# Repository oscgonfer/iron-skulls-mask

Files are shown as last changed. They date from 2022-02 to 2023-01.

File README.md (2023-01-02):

# Iron Skulls Mask - Azul Petróleo

Code and hardware repository for Iron Skulls Azul Petróleo Mask.

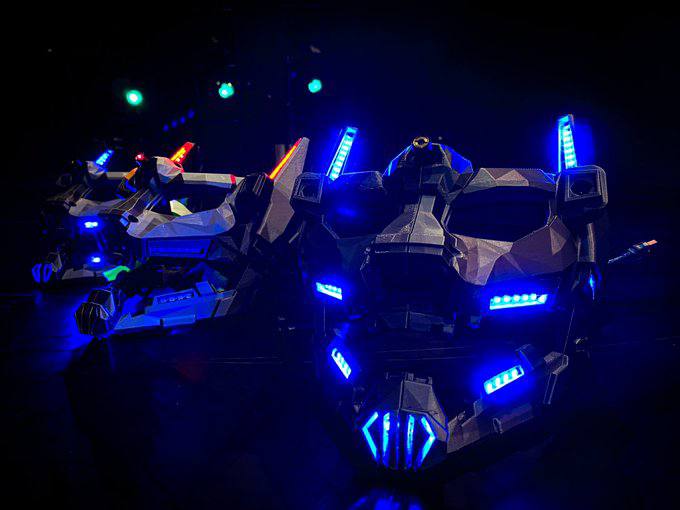
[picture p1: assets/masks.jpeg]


## Model

The mask can be 3D printed in two halves ([left](model/Mask_left.stl) and [right](model/Mask_right.stl)) with supports. Use at least 20% infill to avoid problems in the jaw connection. Both halves can be joined with M3 screws with inserts.

## Electronics

There are 45 addressable RGB LEDs (144led/m, skinny type from [Adafruit](https://www.adafruit.com/product/2969)), 2 very high power [white LEDs](https://www.adafruit.com/product/518) (discontinued?) and 1 [laser pointer](https://www.adafruit.com/product/1056). Everything is controlled by a Feather M0 board, with a RFM69 433MHz radio and powered by a 2000mAh LiPo battery. A shield is used to control the different elements. In addition, an [external antenna](https://www.mouser.es/ProductDetail/815-CAC053010-S433) is used for enhanced reach.

- RGB LEDs are powered directly from the battery, controlled with a single pin from the Feather
- The two high power LEDs are controlled via mosfet, in parallel. The LEDs neeed 3.3V, so a high power LDO is necessary
- The laser is controlled via PWM

A bill of materials is found in the [`hardware/controller`](hardware/controller) folder as well as pcb designs for the feather's shield. The kicad files say it's a Atmega 32u4, which can be, but better to use the Atmel SAMD21 (M0) for the extra Flash memory.

### Power

The feather handles battery charge via it's on board charger. The mask is charged via USB.
Since there are so many LEDs, **at least a 0.5C fast discharge rate battery** is necessary if everything is on. This means that the battery will last 2h at this discharge rate, otherwise, at 0.2C (normal rate), it will last 5h:

| Type | Ratio | Max. Current | Duration (theory) |
| --- | --- | --- | --- |
| Normal | 0.2C | 400mA | 5h |
| Fast | 0.5C | 1A | 2h |

The mask hasn't been tested for full power continuous operation for more than minutes, but it does last >6h in normal operation (not everything on at the same time, all the time).

## Control

The control follows a client-server architecture. Each mask is a server, with an address, and there is a client connected to a computer via USB. The code in both ends is _asynchronous_ so that messages can be sent and arrive to the masks at any time and be responsive.

### Client side

A python script listens to UDP messages and forwards them to a Feather M0 board via USB. This is the [Feather client code](radio/client) (platformio needed). This is the [python script](radio/bridge/bridge.py), using python AsyncIO for serial and OSC/UDP server.

### Server side

A similar code listens on the servers:

- Radiohead is used for receiving packets
- The RGB leds are managed using [NeoPixelBus](https://github.com/Makuna/NeoPixelBus)
- The two high power LEDs and the LED are managed using [JLED](https://github.com/jandelgado/jled)

Animations are static, triggered by a string received via radio, and are stored in [`Animations.h`](radio/server/src/Animations.h). There is a table for describing how the animations are encoded [here](radio/server/src/ANIMATIONS.md).

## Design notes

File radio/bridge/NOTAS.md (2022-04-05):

NOTAS

Hacer los SLINKS (OSC) con WAIT=0, todo con GO

PERRO
Frontales limitarlos hasta acción? o hacerlos cara a público
Interacción laser compleja
Parte final con espacio muy abierto - introducir calles y usar más contra 603

XALAPA
Continuar con mismo ambiente

FINAL XAPALA IR CERRANDO EN EN CENTRO? CHASE?

DIEGO - GUITARRA
Reducir intensidad
CALIDO - INTIMO ---> Hacerlo con convencional en lugar de LED

NOTAS

TODO EN GENERAL MUY ABIERTO
CALLE LATERAL BIEN
CUANDO ENTRA LA MASCARA

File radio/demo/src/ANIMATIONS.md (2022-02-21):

## LEDSTRIP ANIMATIONS

__ __ __
|  |  |
|  |  |__ F: FAST / S: SLOW
|  |
|  |__ F: FADE / L: LOOP
|
|__ A: ALL / E: EYES / O: EARS

### Full Table

| CODE | DESCRIPTION | PARAM |
| :-: | :- | :- |
| "AFF"  | ALL FADE FAST | COLOR (RGB_HEX) |
| "AFS"  | ALL FADE SLOW | COLOR (RGB_HEX) |
| "ALF"  | ALL LOOP FAST | COLOR (RGB_HEX) |
| "ALS"  | ALL LOOP SLOW | COLOR (RGB_HEX) |
| "EFF"  | EYES FADE FAST | COLOR (RGB_HEX) |
| "EFS"  | EYES FADE SLOW | COLOR (RGB_HEX) |
| "ELF"  | EYES LOOP FAST | COLOR (RGB_HEX) |
| "ELS"  | EYES LOOP SLOW | COLOR (RGB_HEX) |
| "OFF"  | EARS FADE FAST | COLOR (RGB_HEX) |
| "OFS"  | EARS FADE SLOW | COLOR (RGB_HEX) |
| "OLF"  | EARS LOOP FAST | COLOR (RGB_HEX) |
| "OLS"  | EARS LOOP SLOW | COLOR (RGB_HEX) |

### Example

```
AFF/00FF00
--> All Leds Fade-in to Green
```

## PWM ANIMATIONS (LASER OR HIGH POWER LEDS)

__ __ __
|  |  |
|  |  |__ S: SHOT / F: FOREVER
|  |
|  |__ F: FADE / R: BREATHE / L: BLINK
|
|__ L: LASER / F: FRONTLIGHTS

### Full Table

| CODE | DESCRIPTION | PARAM | 
| :-: | :- | :- |
| "LFF"  | LASER FADE-TO FAST | INTENSITY |
| "LFS"  | LASER FADE-TO SLOW | INTENSITY |
| "LRF"  | LASER BREATH FOREVER | PERIOD |
| "LLF"  | LASER BLINK FOREVER | PERIOD |
| "LRS"  | LASER BREATH SHOT_NUM-SHOTs | PERIOD |
| "LLS"  | LASER BLINK SHOT_NUM-SHOTs | PERIOD |
| "FFF"  | FRONT FADE-TO FAST | INTENSITY |
| "FFS"  | FRONT FADE-TO SLOW | INTENSITY |
| "FRF"  | FRONT BREATH FOREVER | PERIOD |
| "FLF"  | FRONT BLINK FOREVER | PERIOD |
| "FRS"  | FRONT BREATH SHOT_NUM-SHOTs | PERIOD |
| "FLS"  | FRONT BLINK SHOT_NUM-SHOTs | PERIOD |

### Example

```
FRF/3000
--> Front Lights Breathe Forever with 3000ms PERIOD
```

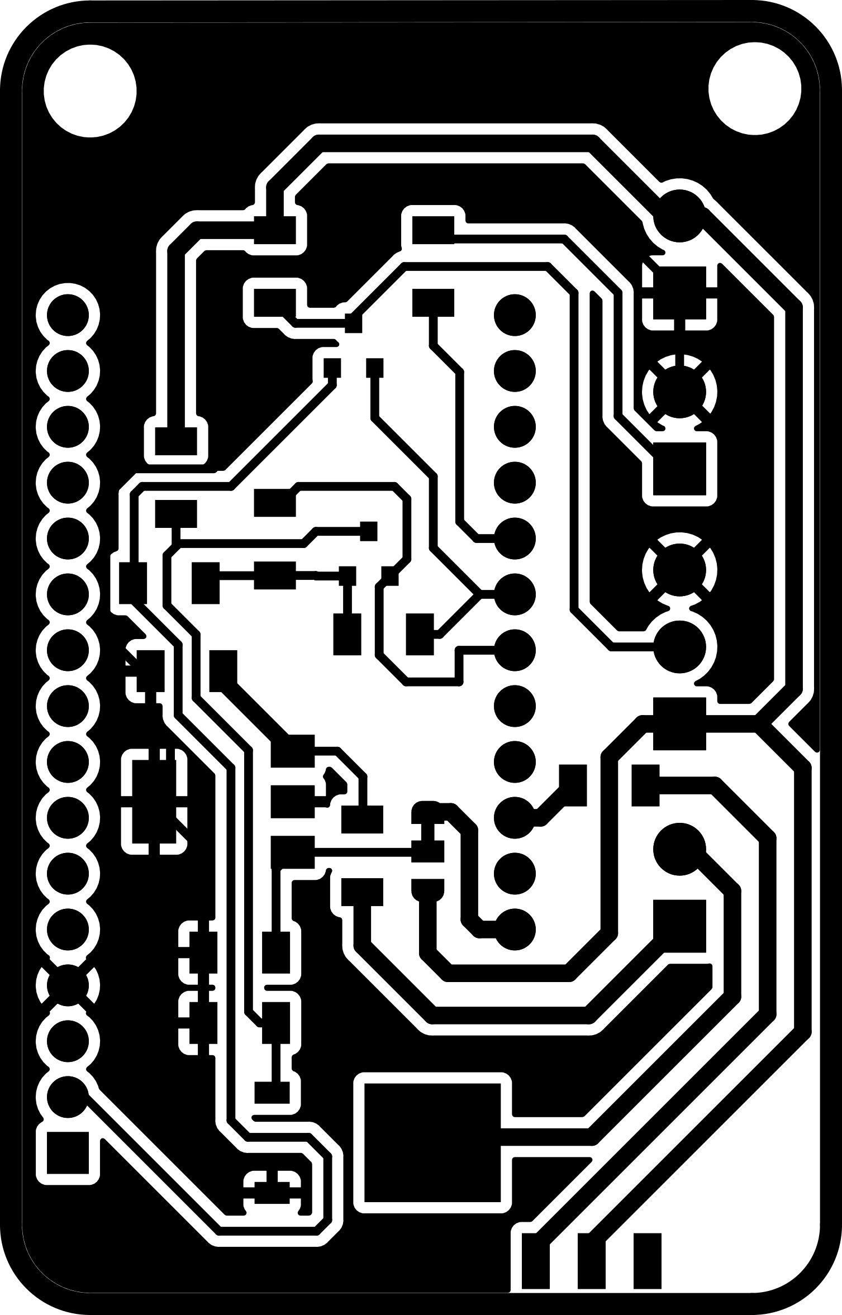
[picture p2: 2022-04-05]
hardware/controller/exports/fab/traces_2.png

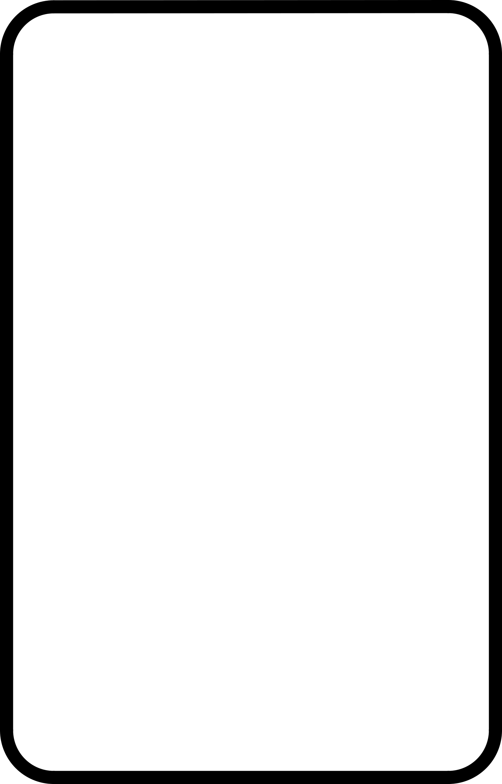
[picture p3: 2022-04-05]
hardware/controller/exports/fab/outline_2.png

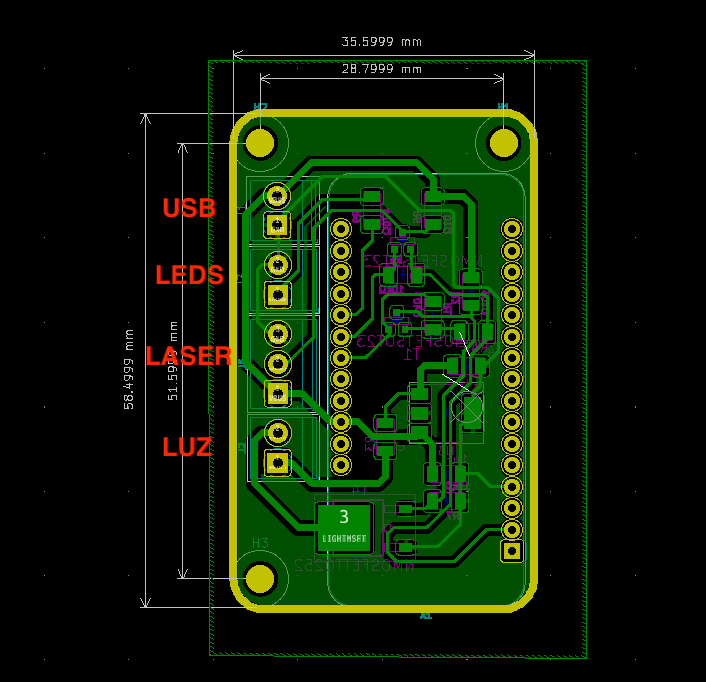
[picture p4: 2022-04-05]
hardware/controller/exports/fab/esquema.png

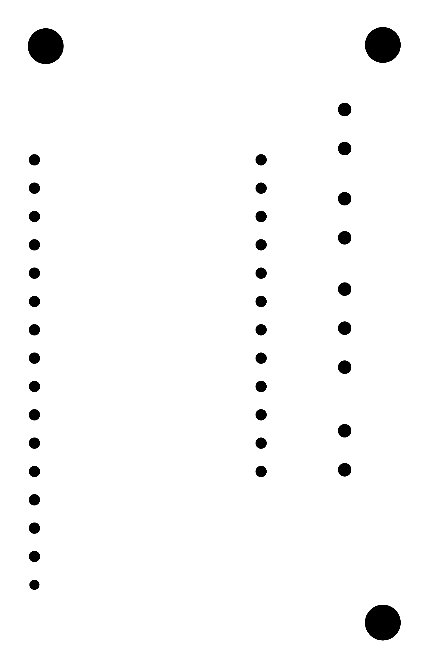
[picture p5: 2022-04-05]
hardware/controller/exports/fab/holes_2.png

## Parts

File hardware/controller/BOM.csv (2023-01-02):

SHIELD
Item | Qty | Reference(s) | Value | LibPart | Footprint | Datasheet
1 | 1 | A1 | Adafruit_Feather_32u4_BluefruitLE | MCU_Module:Adafruit_Feather_32u4_BluefruitLE | Module:Adafruit_Feather | https://cdn-learn.adafruit.com/downloads/pdf/adafruit-feather-32u4-bluefruit-le.pdf
2 | 1 | C3 | 1uF | fab:CAP-UNPOLARIZEDFAB | fab-C1206FAB
3 | 1 | C4 | 4.7uF | fab:CAP-UNPOLARIZEDFAB | fab-C1206FAB
4 | 3 | H1, H2, H3 | MountingHole | Mechanical:MountingHole | MountingHole:MountingHole_3.2mm_M3 | ~
5 | 3 | J1, J2, J3 | Screw_Terminal_01x02 | Connector:Screw_Terminal_01x02 | TerminalBlock_Phoenix:TerminalBlock_Phoenix_PT-1,5-2-3.5-H_1x02_P3.50mm_Horizontal | ~
6 | 1 | J5 | Screw_Terminal_01x03 | Connector:Screw_Terminal_01x03 | TerminalBlock_Phoenix:TerminalBlock_Phoenix_PT-1,5-3-3.5-H_1x03_P3.50mm_Horizontal | ~
7 | 1 | JP1 | Jumper_3_Bridged12 | Jumper:Jumper_3_Bridged12 | Jumper:SolderJumper-3_P1.3mm_Bridged12_RoundedPad1.0x1.5mm_NumberLabels | ~
8 | 5 | R1, R2, R5, R6, R7 | 10kΩ | Device:R_US | fab:fab-R1206FAB | ~
9 | 3 | R3, R4, R8 | 0 | Device:R_US | fab:fab-R1206FAB | ~
10 | 1 | R9 | 470Ω | Device:R_US | fab:fab-R1206FAB | ~
11 | 1 | SW1 | SW_SPDT | Switch:SW_SPDT | fab:fab-SPDTSWITCH | ~
12 | 2 | T1, T3 | NMOSFETSOT23 | fab:NMOSFETSOT23 | fab-SOT-23
13 | 1 | T4 | NMOSFETTO252 | fab:NMOSFETTO252 | fab-TO252
14 | 1 | U3 | AP7361C-33E | Regulator_Linear:AP7361C-33E | Package_TO_SOT_SMD:SOT-223-3_TabPin2 | https://www.diodes.com/assets/Datasheets/AP7361C.pdf
LIGHTS
Item | Qty | Description | Manufacturer and PN | Mouser Link
1 | 1 | Laser pointer | TTL Laser Diode - 5mW 650nm Red - 50KHz Max | https://www.adafruit.com/product/1056
1 | 2 | High power White LEDs | 1 Watt Cool White LED - Heatsink Mounted | https://www.adafruit.com/product/518
1 | 1 | NeoPixel 144led/m skinny | Adafruit Mini Skinny NeoPixel Digital RGB LED Strip - 144 LED/m - 1m WHITE | https://www.adafruit.com/product/2969
EXTRAS
Item | Qty | Description | Manufacturer and PN | Mouser Link
1 | 1 | 433MHz Antenna | Abracon AEACAC053010-S433 | https://eu.mouser.com/ProductDetail/815-CAC053010-S433

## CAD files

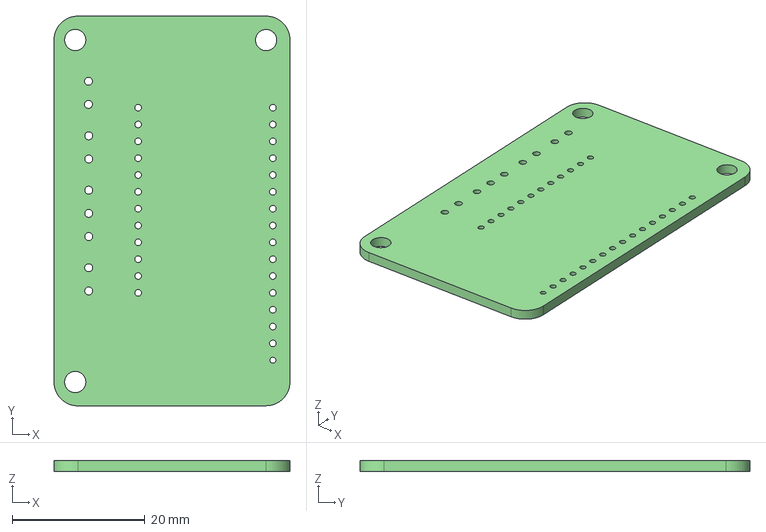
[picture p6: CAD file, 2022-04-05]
hardware/controller/exports/fab/controller.step
35.6 x 58.8 x 1.60 mm

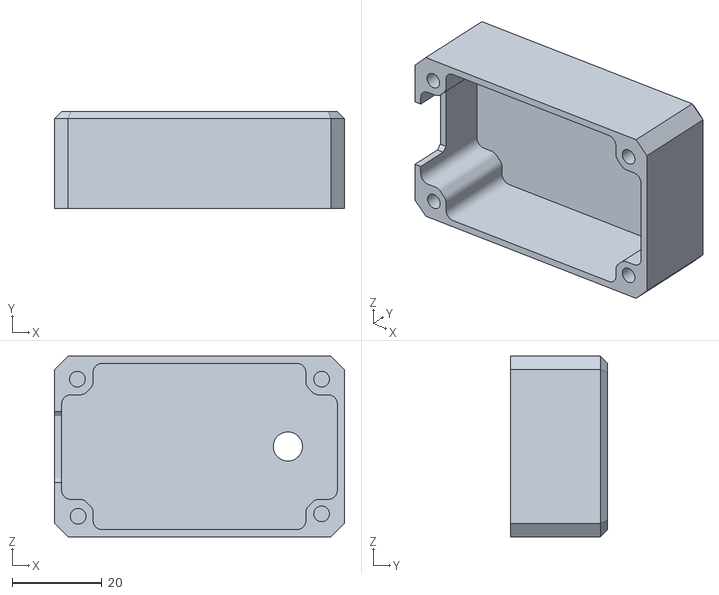
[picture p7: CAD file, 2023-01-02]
model/emitter-cover-v1.stl
64.5 x 21.6 x 40.2

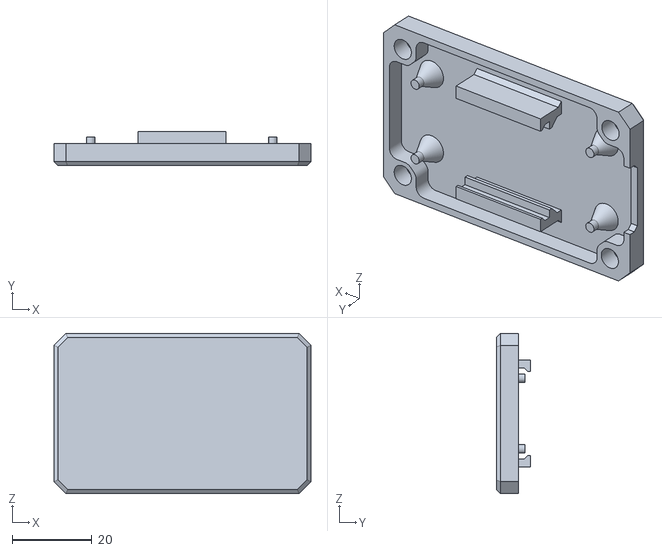
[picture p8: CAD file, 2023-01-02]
model/emitter-base-v1.stl
64.5 x 8.60 x 40.2

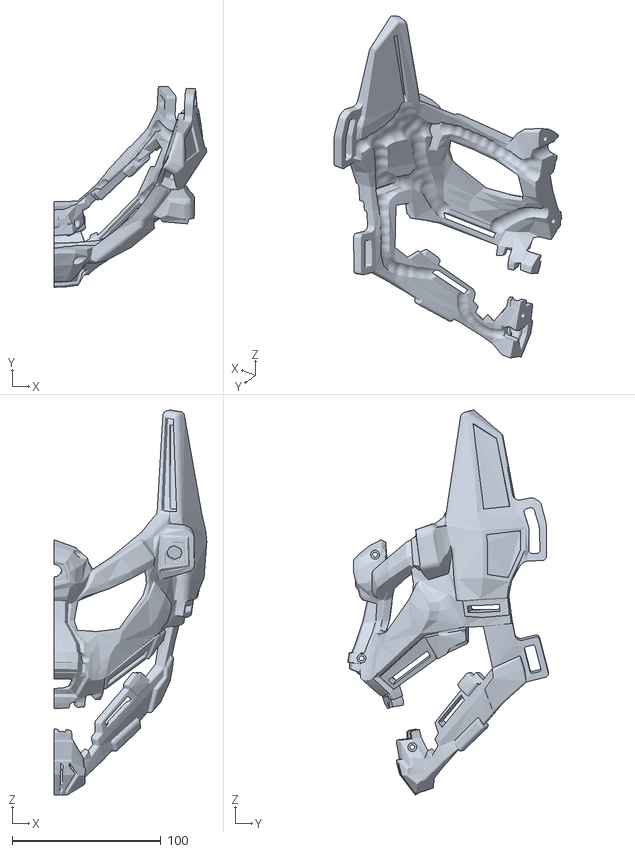
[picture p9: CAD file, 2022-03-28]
model/Mask_right.stl
102.7 x 134.9 x 258.8

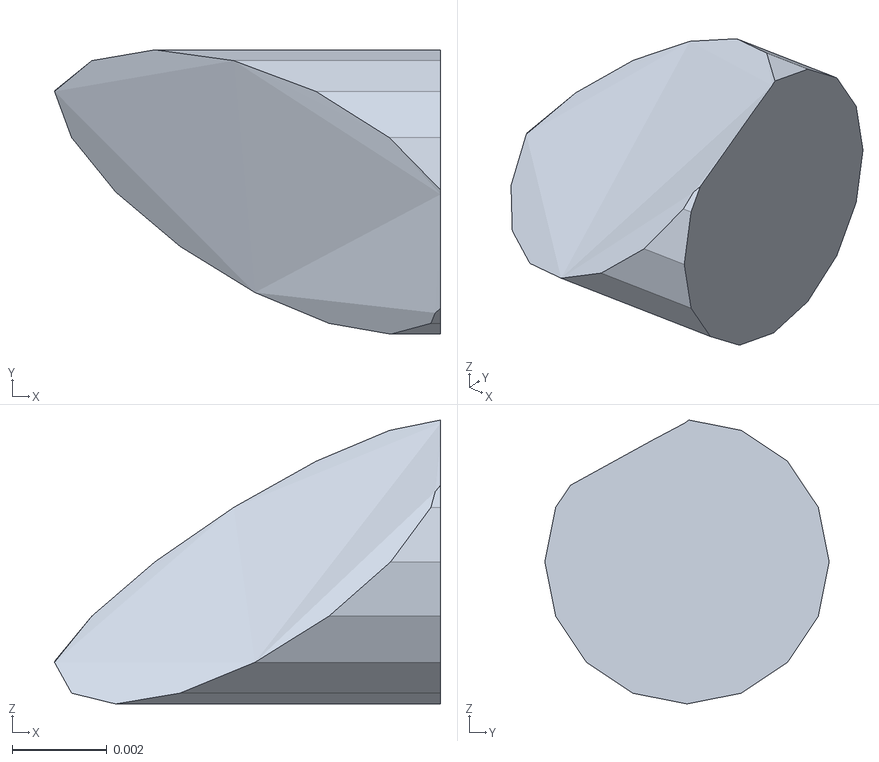
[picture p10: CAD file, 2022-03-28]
model/Mask_cap_top.stl
0.00815 x 0.006 x 0.00599

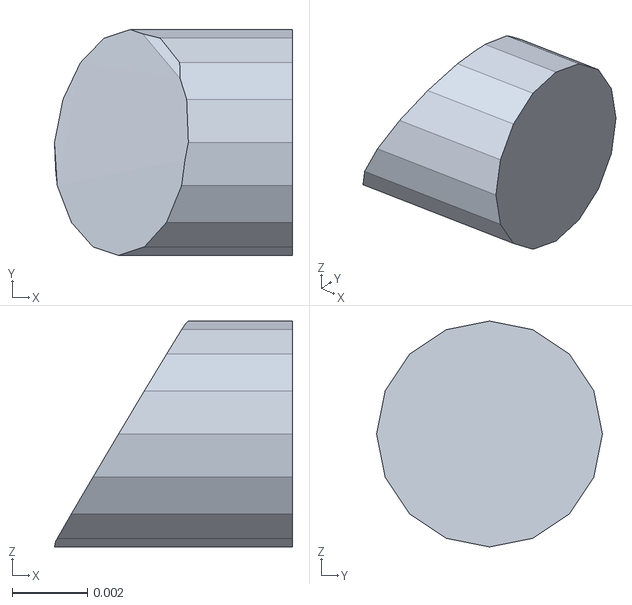
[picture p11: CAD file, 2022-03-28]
model/Mask_cap_bottom.stl
0.00632 x 0.006 x 0.006

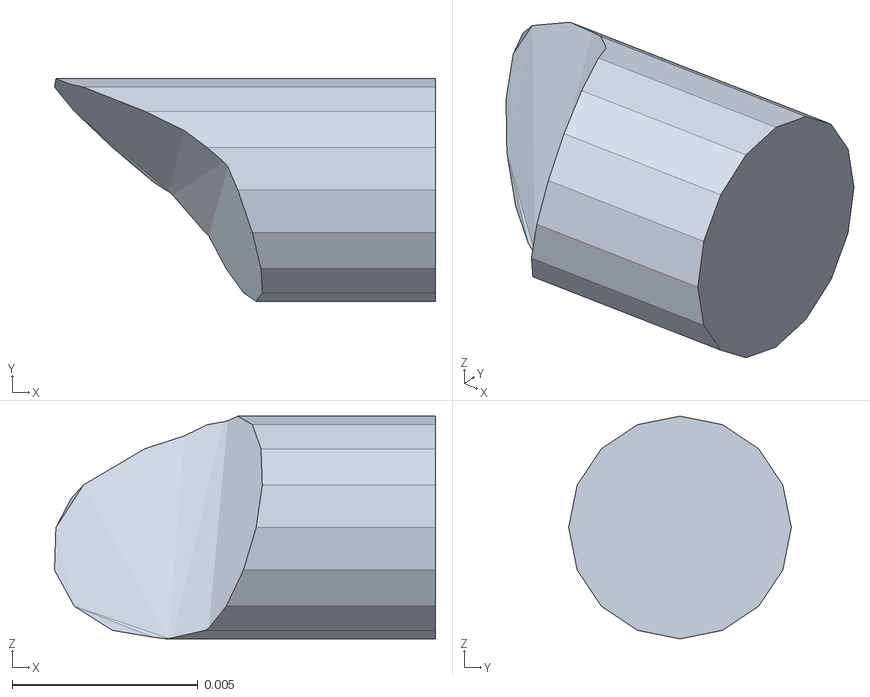
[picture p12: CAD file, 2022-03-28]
model/Mask_cap_middle.stl
0.0103 x 0.006 x 0.006

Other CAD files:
model/Mask_left.stl
hardware/controller/exports/fab/controller.stl
model/Mask.blend

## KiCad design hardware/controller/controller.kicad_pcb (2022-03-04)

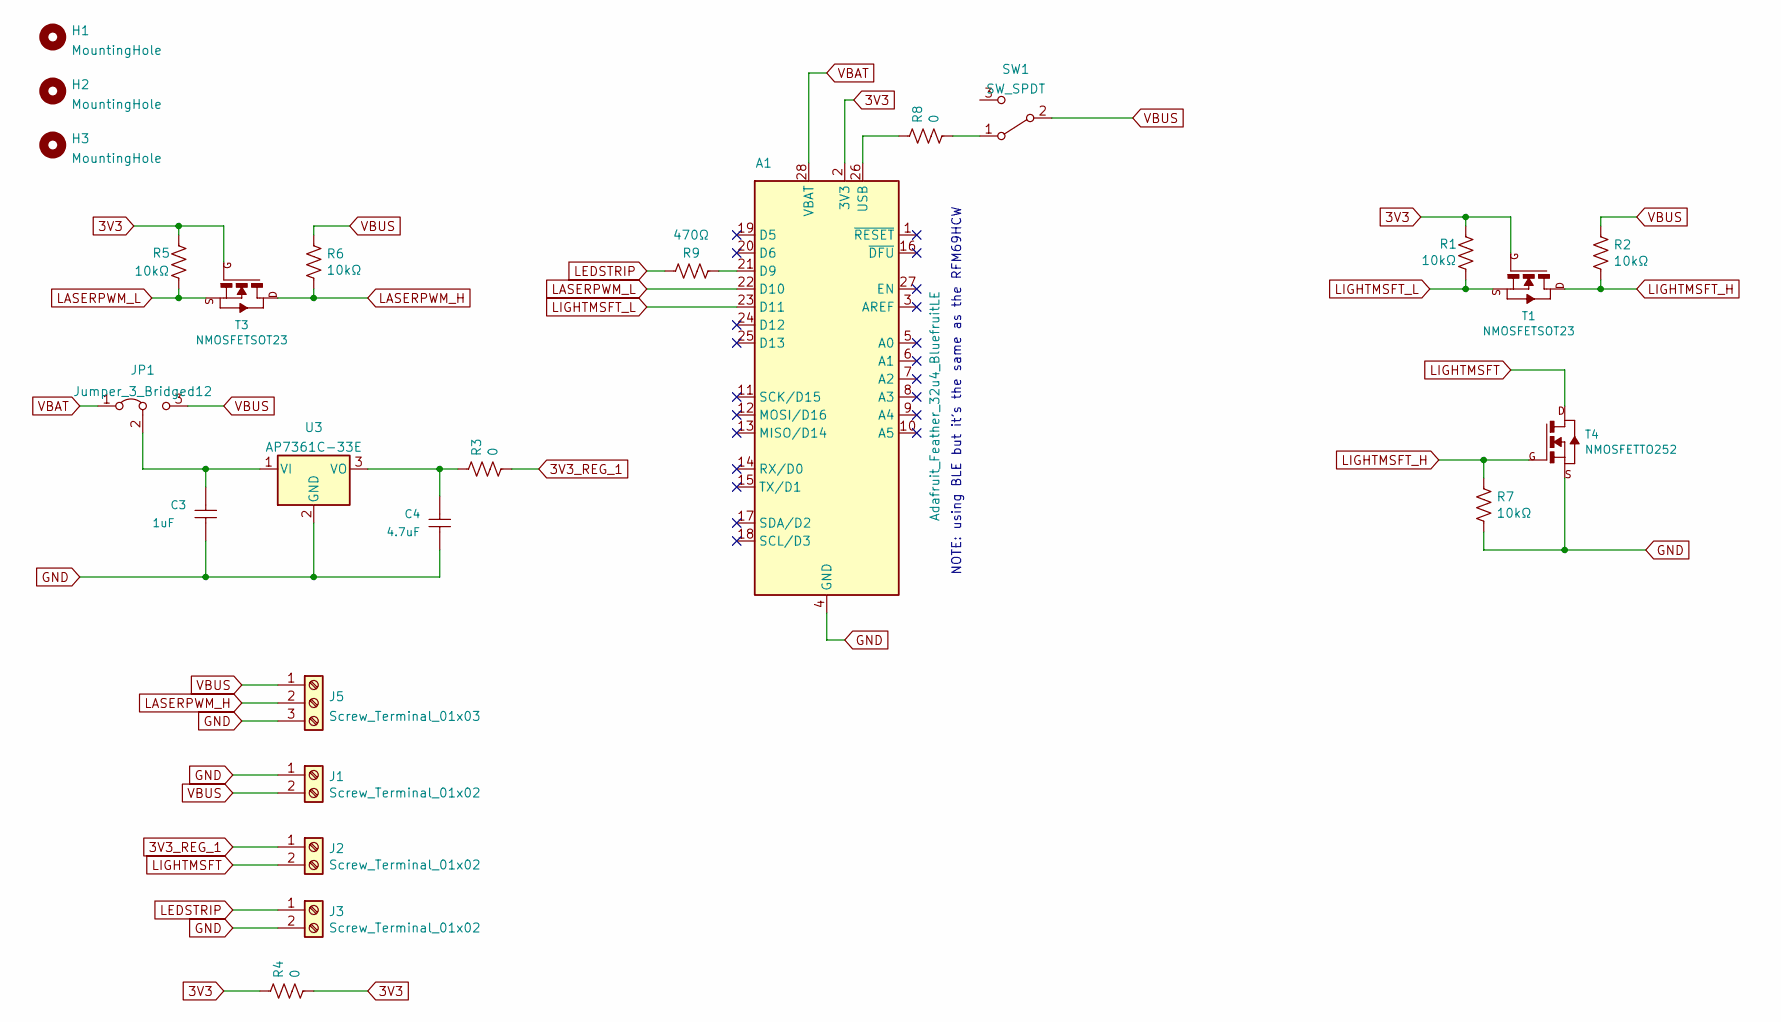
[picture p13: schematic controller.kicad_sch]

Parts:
A1: Adafruit_Feather_32u4_BluefruitLE; Adafruit_Feather
C3: 1uF; fab-C1206FAB
C4: 4.7uF; fab-C1206FAB
H1, H2, H3: MountingHole; MountingHole_3.2mm_M3
J1, J2, J3: Screw_Terminal_01x02; TerminalBlock_Phoenix_PT-1,5-2-3.5-H_1x02_P3.50mm_Horizontal
J5: Screw_Terminal_01x03; TerminalBlock_Phoenix_PT-1,5-3-3.5-H_1x03_P3.50mm_Horizontal
JP1: Jumper_3_Bridged12; SolderJumper-3_P1.3mm_Bridged12_RoundedPad1.0x1.5mm_NumberL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
R1, R2, R5, R6, R7: 10kΩ; fab-R1206FAB
R3, R4, R8: 0; fab-R1206FAB
R9: 470Ω; fab-R1206FAB
SW1: SW_SPDT; fab-SPDTSWITCH
T1, T3: NMOSFETSOT23; fab-SOT-23
T4: NMOSFETTO252; fab-TO252
U3: AP7361C-33E; SOT-223-3_TabPin2

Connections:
3V3: A1.2 (3V3), R1.1, R4.1, R4.2, R5.1, T1.3 (G), T3.3 (G)
3V3_REG_1: J2.1, R3.2
GND: A1.4 (GND), C3.2, C4.2, J1.1, J3.2, J5.3, R7.2, T4.2 (S), U3.2 (GND)
LASERPWM_H: J5.2, R6.2, T3.1 (D)
LASERPWM_L: A1.22 (D10), R5.2, T3.2 (S)
LEDSTRIP: J3.1, R9.1
LIGHTMSFT: J2.2, T4.3 (D)
LIGHTMSFT_H: R2.2, R7.1, T1.1 (D), T4.1 (G)
LIGHTMSFT_L: A1.23 (D11), R1.2, T1.2 (S)
unnamed: A1.21 (D9), R9.2
unnamed: A1.26 (USB), R8.1
unnamed: C3.1, JP1.2 (C), U3.1 (VI)
unnamed: C4.1, R3.1, U3.3 (VO)
unnamed: R8.2, SW1.1 (A)
VBAT: A1.28 (VBAT), JP1.1 (A)
VBUS: J1.2, J5.1, JP1.3 (B), R2.1, R6.1, SW1.2 (B)

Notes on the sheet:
NOTE: using BLE but it’s the same as the RFM69HCW

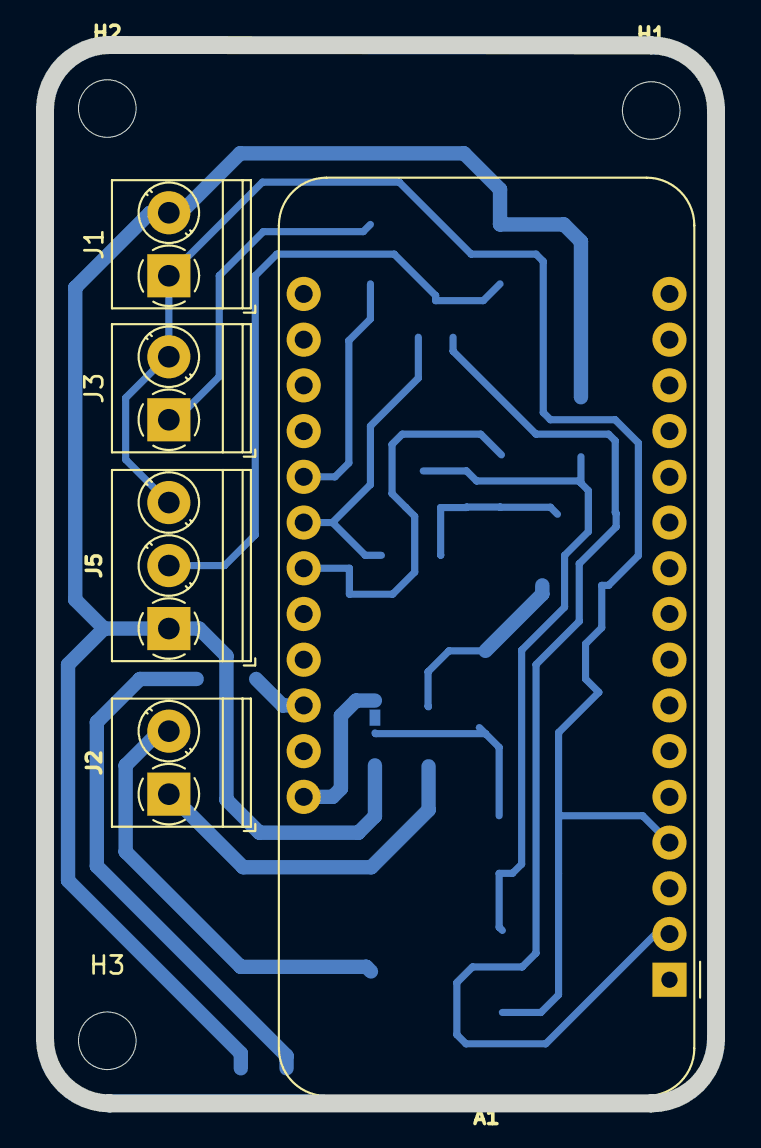
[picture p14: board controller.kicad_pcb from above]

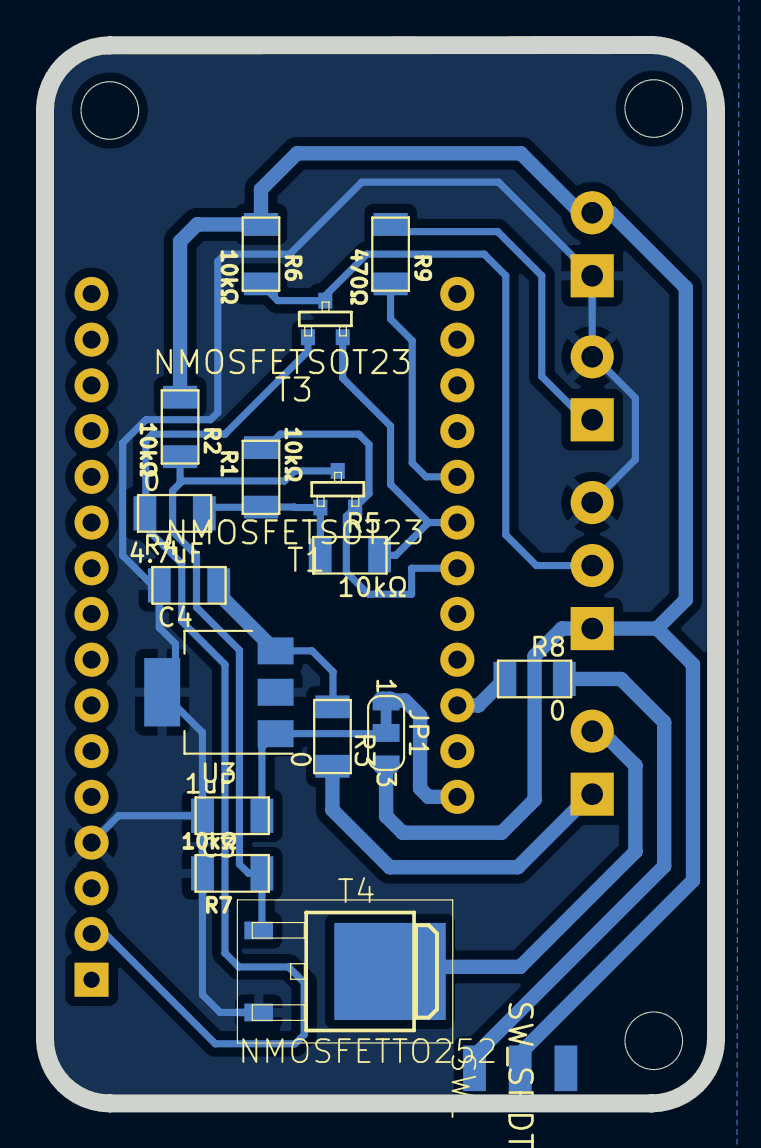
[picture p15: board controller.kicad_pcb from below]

Board: 2 copper layers, 37.3 x 58.8 mm, 25 parts (17 on the bottom side), 16 nets.

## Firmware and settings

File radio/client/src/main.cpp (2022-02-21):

#include "Arduino.h"
#include <SPI.h>
#include <RH_RF69.h>
#include <RHMesh.h>

//RADIO
#define CLIENT_ADDRESS      1
#define REPEATER1_ADDRESS   2
#define REPEATER2_ADDRESS   3
#define BASE1_ADDRESS       4
#define BASE2_ADDRESS       5
#define BASE3_ADDRESS       6
#define BASE4_ADDRESS       7
// MASKS WILL START AT 10 TO HAVE ROOM FOR MORE REPEATERS/BASES
#define MASK1_ADDRESS       10
#define MASK2_ADDRESS       11
#define MASK3_ADDRESS       12
#define MASK4_ADDRESS       13
#define BROADCAST_DEST      99

#define RF69_FREQ           433.0
#define RFM69_CS            8
#define RFM69_RST           4

#if defined (__AVR_ATmega32U4__) // Feather 32u4 w/Radio
#define RFM69_INT           7
#else
#define RFM69_INT           3
#endif

#define LED                 13

// 20 bytes max length means at maximum 2 bytes for checksum and 18 for message itself
#define MAX_MESSAGE_LENGTH  20

RH_RF69 rf69(RFM69_CS, RFM69_INT);
RHMesh rf69_manager(rf69, CLIENT_ADDRESS);

int16_t packetnum = 0;  // packet counter, we increment per xmission
char checksum_ok[] = "CHK_OK";
uint8_t buf[RH_RF69_MAX_MESSAGE_LEN];

void setup()
{
    Serial.begin(115200);
    // while (!Serial) { delay(1); } // wait until serial console is open, remove if not tethered to computer

    pinMode(LED, OUTPUT);
    digitalWrite(LED, HIGH);
    pinMode(RFM69_RST, OUTPUT);
    digitalWrite(RFM69_RST, LOW);

    // manual reset
    digitalWrite(RFM69_RST, HIGH);
    delay(10);
    digitalWrite(RFM69_RST, LOW);
    delay(10);

    if (!rf69_manager.init()) {
        Serial.println("RFM69 radio init failed");
        while (1);
    }

    // Manually define the routes for this network
    rf69_manager.addRouteTo(REPEATER1_ADDRESS, REPEATER1_ADDRESS);
    rf69_manager.addRouteTo(REPEATER2_ADDRESS, REPEATER2_ADDRESS);
    rf69_manager.addRouteTo(BASE1_ADDRESS, BASE1_ADDRESS);
    rf69_manager.addRouteTo(BASE2_ADDRESS, BASE2_ADDRESS);
    rf69_manager.addRouteTo(BASE3_ADDRESS, BASE3_ADDRESS);
    rf69_manager.addRouteTo(BASE4_ADDRESS, BASE4_ADDRESS);
    // rf69_manager.addRouteTo(MASK1_ADDRESS, MASK1_ADDRESS);
    // rf69_manager.addRouteTo(MASK2_ADDRESS, MASK2_ADDRESS);
    // rf69_manager.addRouteTo(MASK3_ADDRESS, MASK3_ADDRESS);
    // rf69_manager.addRouteTo(MASK4_ADDRESS, MASK4_ADDRESS);

    Serial.println("RFM69 radio init OK!");
    // Defaults after init are 434.0MHz, modulation GFSK_Rb250Fd250, +13dbM (for low power module)
    // No encryption
    if (!rf69.setFrequency(RF69_FREQ)) {
        Serial.println("setFrequency failed");
    }

    // If you are using a high power RF69 eg RFM69HW, you *must* set a Tx power with the
    // ishighpowermodule flag set like this:
    rf69.setTxPower(20, true);  // range from 14-20 for power, 2nd arg must be true for 69HCW

    // The encryption key has to be the same as the one in the server
    uint8_t key[] = { 0x01, 0x02, 0x03, 0x04, 0x05, 0x06, 0x07, 0x08,
                      0x01, 0x02, 0x03, 0x04, 0x05, 0x06, 0x07, 0x08};
    rf69.setEncryptionKey(key);

    // Serial.print("RFM69 radio @");  Serial.print((int)RF69_FREQ);  Serial.println(" MHz");
}


void loop() {
  
    static char message[MAX_MESSAGE_LENGTH];
    static unsigned int message_pos = 0;
    digitalWrite(LED, HIGH);

    while (Serial.available() > 0) {

        // read the incoming byte:
        byte inByte = Serial.read();
        if (inByte != '\n') {

            message[message_pos] = inByte;
            message_pos++;

        } else {
            digitalWrite(LED, LOW);

            message[message_pos] = '\0';
            message_pos = 0;

            Serial.println("Got new message to send");

            Serial.println(message);
            char d1 = message[0];
            char d2 = message[1];
            char d[2] = {d1, d2};
            int destination = String(d).toInt();
            // If destination is broadcast destination (99) use 255 from RH
            if (destination == BROADCAST_DEST) {
                destination = RH_BROADCAST_ADDRESS;
            }
            Serial.print("Destination: ");
            Serial.println(destination);
            
            char packet[MAX_MESSAGE_LENGTH]{};
            strcpy(packet, &message[2]);
            int packet_length = strlen(packet);

            Serial.print("Packet: ");
            Serial.println(packet);

            Serial.print("Packet lenght ");
            Serial.println(packet_length);

            uint16_t checksum = 0;

            for (int i = 0; i < packet_length; i++) {
                // Serial.println(packet[i], HEX);
                checksum += packet[i];
            }
            
            Serial.print("Checksum: ");
            Serial.println(checksum, HEX);

            packet[packet_length++] = (uint8_t)(checksum >> 8);
            packet[packet_length++] = (uint8_t)(checksum & 0xFF);
            packet[packet_length] =  '\0';
            Serial.print("New packet length: ");
            Serial.println(strlen(packet));

            // for (int i = 0; i < strlen(packet); i++) {
            //     Serial.println(packet[i], HEX);
            // }

            bool responseReceived = false;

            while (!responseReceived) {

                // Check if we got another message to send
                if (Serial.available()>0){
                    break;
                }

                Serial.print("Sending ");
                Serial.println(packet);

                Serial.println("Sending it...");

                if (rf69_manager.sendtoWait((uint8_t *)packet, strlen(packet), destination) == RH_ROUTER_ERROR_NONE) {
                    digitalWrite(LED, HIGH);
                    // Now wait for a reply from the server
                    uint8_t len = sizeof(buf);
                    uint8_t from;

                    if (rf69_manager.recvfromAckTimeout(buf, &len, 2000, &from)) {
                        buf[len] = 0; // zero out remaining string

                        Serial.print("Got reply from #"); Serial.print(from);
                        Serial.print(" [RSSI :");
                        Serial.print(rf69.lastRssi());
                        Serial.print("] : ");
                        Serial.println((char*)buf);

                        if (strstr((char*)buf, checksum_ok)) {
                            // Checksum OK
                            responseReceived = true;
                        } else {
                            Serial.println((char*) buf);
                        }

                    } else {
                        Serial.println("No reply, is anyone listening?");
                    }
                } else {
                    Serial.println("Sending failed (no ack)");
                }
            }
        }
    }
}

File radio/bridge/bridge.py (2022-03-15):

import asyncio
import serial_asyncio
from ports import serial_ports, get_radio
from pythonosc.dispatcher import Dispatcher
from patch import names
from pythonosc.osc_server import AsyncIOOSCUDPServer
from typing import List, Any
import time

# OSC Server IP
SERVER_IP = "127.0.0.1"
SERVER_PORT = 5005
# UDP Message filter
UDP_FILTER = "/mask/*"
# Serial baudrate
BAUD = 115200

def std_out(msg, who):
    print (f'[{who}]: {msg}')

# Run this to make a forever loop with no sleep
async def loop():
    while True:
        await asyncio.sleep(0)

class Bridge(object):
    """
        Makes a bridge between an OSC-UDP async server and a serial
        device. The UDP input is forwarded with some
    """
    def __init__(self):
        super(Bridge, self).__init__()

    async def main(self, dispatcher):

        server = AsyncIOOSCUDPServer((SERVER_IP, SERVER_PORT), dispatcher,
                                     asyncio.get_event_loop())
        transport, protocol = await server.create_serve_endpoint()  # Create datagram endpoint and start serving

        # Make async serial connection
        self.reader, self.writer = await serial_asyncio.open_serial_connection(url=get_radio().device, baudrate=115200)

        received = await self.recv(self.reader)
        await loop()
        transport.close()  # Clean up serve endpoint

    def send(self, *args: List[Any]) -> None:
        std_out (f'{args[0]}\n', 'BRIDGE')
        std_out (time.strftime("%H:%M:%S %d-%m-%Y"), 'BRIDGE')

        # We just remove the UDP_FILTER
        msg = args[0].strip(UDP_FILTER[:-1]).upper()
        address = msg[0:msg.index('/')]
        if address in names:
            msg = msg.replace(address, str(names[address]))

        std_out(f'Sending message: {msg}', 'BRIDGE')
        # TODO make it compatible with multiple
        # masks at the same time
        self.writer.write(f'{msg}\n'.encode('utf-8'))

    async def recv(self, r):
        while True:
            msg = await r.readline()
            try:
                decmsg = msg.rstrip().decode()
                std_out (decmsg, 'DEVICE')
            except:
                pass

bridge = Bridge()
dispatcher = Dispatcher()
# Filter OSC messages by "/mask"
dispatcher.map(UDP_FILTER, bridge.send)
# Run main bridge loop
asyncio.run(bridge.main(dispatcher))

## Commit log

2022-01-16 Add first schematic for pcb
    [controller.kicad_pcb, controller.sch]
2022-02-06 Add overkill controller version
    [controller.kicad_pcb, controller.kicad_sch]
2022-02-13 Last version of controller
    [controller v1.step, controller.kicad_pcb, controller.kicad_sch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]
2022-02-23 Modify enttec.py for OSC only on current levels
2022-03-04 electronics with separate power sources and switch
    [controller.kicad_pcb, controller.kicad_sch]
2022-03-15 Lava version with reduced leds
2022-03-16 Fix update after laser fade slow
    [main.cpp]
2022-03-28 Added mask models
    [Mask.blend, Mask_cap_bottom.stl, Mask_cap_middle.stl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]
2022-04-05 Fix python additional eos and udp scripts
    [bridge_eos_dlight.py, patch.py, test_udp.py]
2022-04-05 Remove exports
    [controller v1.step, controller.step, controller.stl]
2023-01-02 Improve documentation for the mask
    [BOM.csv, controller v1.step, controller.sch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]
